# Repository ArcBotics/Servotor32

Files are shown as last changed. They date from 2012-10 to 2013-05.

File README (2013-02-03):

All hardware for Servotor32 is licensed under a Creative Commons Attribution ShareAlike 3.0 United States License.
The full terms of this license can be read at:
http://creativecommons.org/licenses/by-sa/3.0/

All software is licensed under the MIT License.
Permission is hereby granted, free of charge, to any person obtaining a copy of this software and associated documentation files (the "Software"), to deal in the Software without restriction, including without limitation the rights to use, copy, modify, merge, publish, distribute, sublicense, and/or sell copies of the Software, and to permit persons to whom the Software is furnished to do so, subject to the following conditions:

The above copyright notice and this permission notice shall be included in all copies or substantial portions of the Software.

THE SOFTWARE IS PROVIDED "AS IS", WITHOUT WARRANTY OF ANY KIND, EXPRESS OR IMPLIED, INCLUDING BUT NOT LIMITED TO THE WARRANTIES OF MERCHANTABILITY, FITNESS FOR A PARTICULAR PURPOSE AND NONINFRINGEMENT. IN NO EVENT SHALL THE AUTHORS OR COPYRIGHT HOLDERS BE LIABLE FOR ANY CLAIM, DAMAGES OR OTHER LIABILITY, WHETHER IN AN ACTION OF CONTRACT, TORT OR OTHERWISE, ARISING FROM, OUT OF OR IN CONNECTION WITH THE SOFTWARE OR THE USE OR OTHER DEALINGS IN THE SOFTWARE.

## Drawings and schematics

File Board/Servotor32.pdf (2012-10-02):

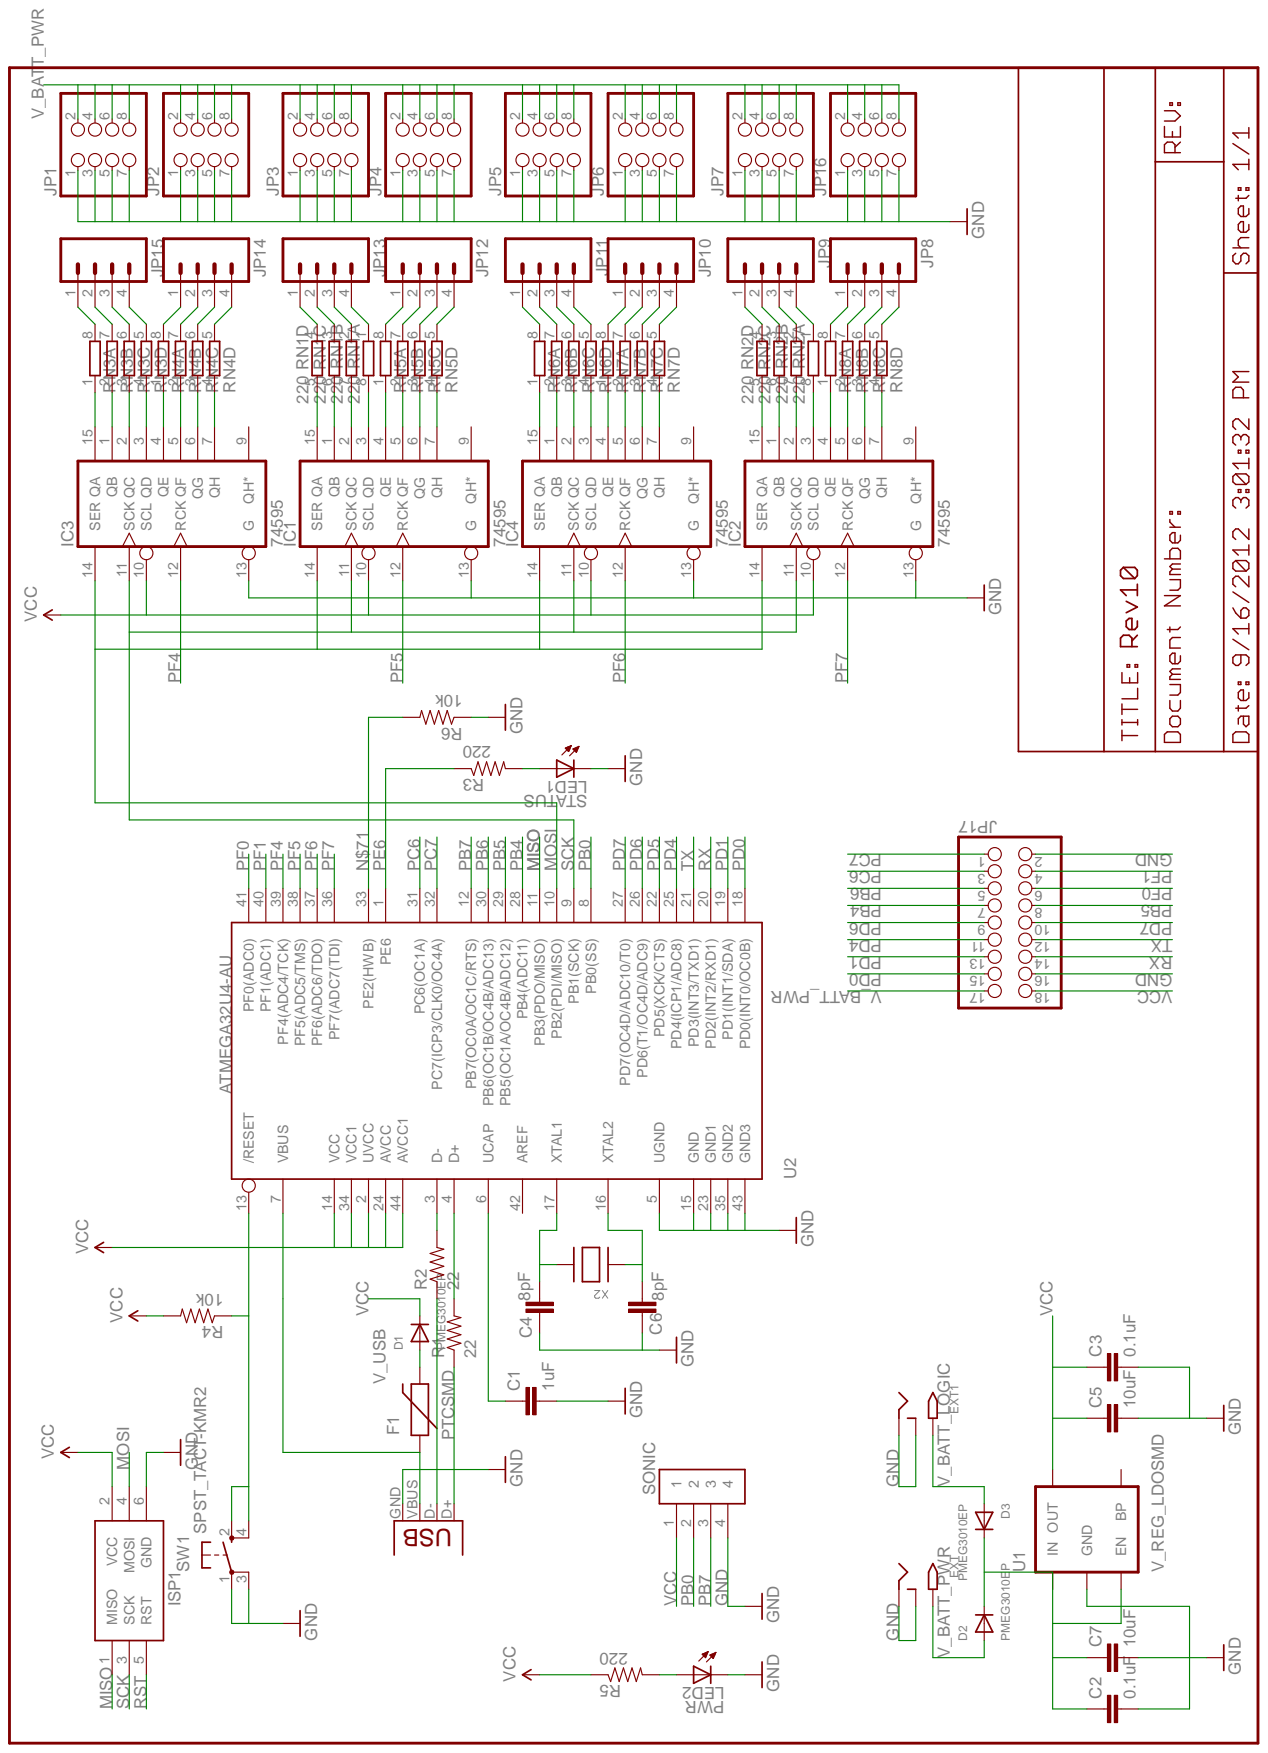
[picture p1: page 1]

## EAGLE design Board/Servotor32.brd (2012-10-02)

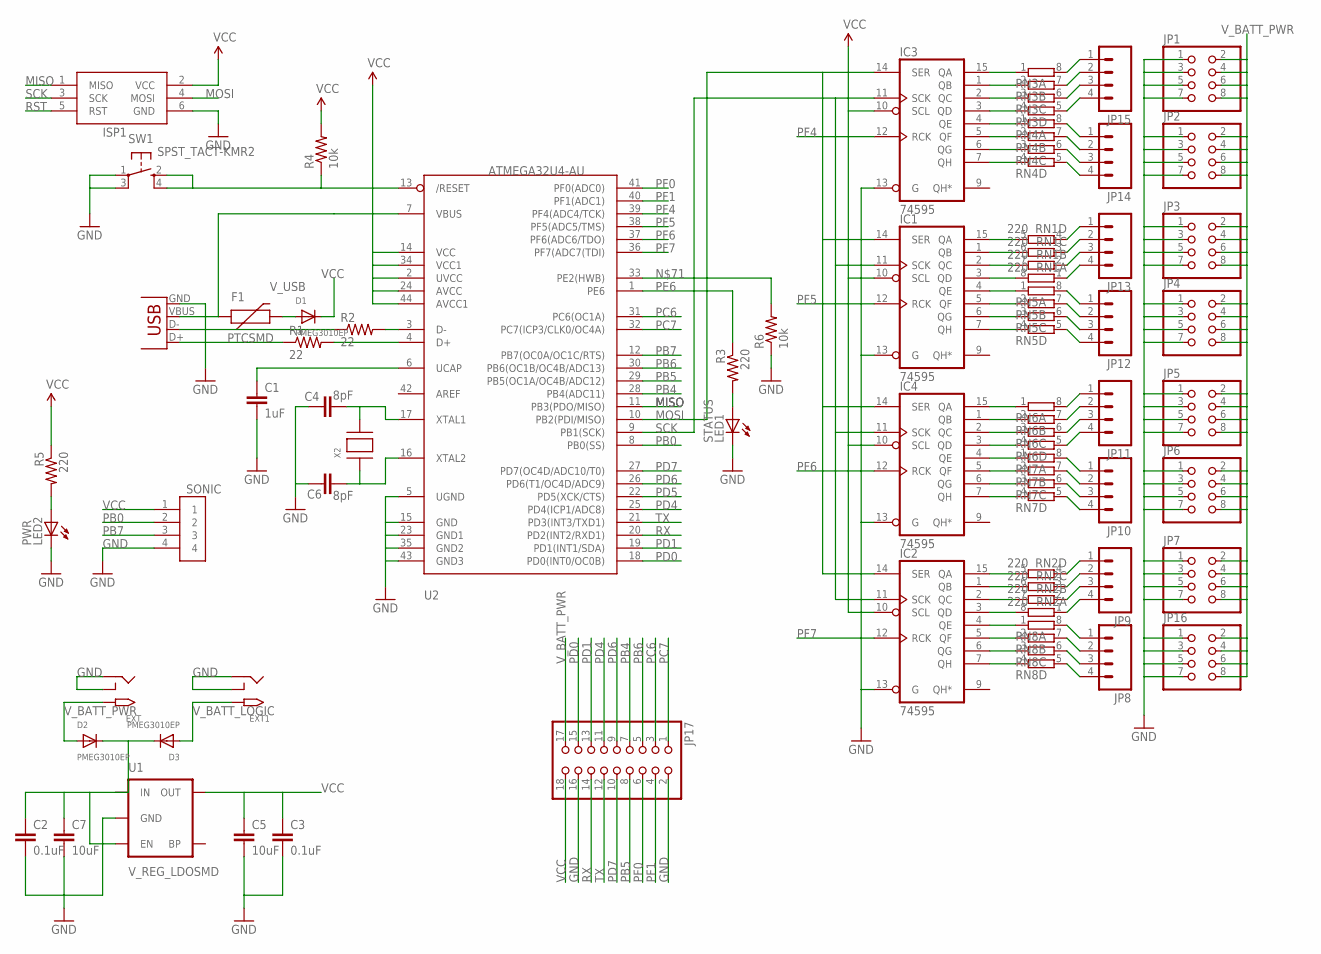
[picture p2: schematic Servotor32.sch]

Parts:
C1: 1uF; 0603-CAP
C2, C3: 0.1uF; 0603-CAP
C4, C6: 8pF; 0603-CAP
C5, C7: 10uF; 0805
D1, D2, D3: PMEG3010EP; SOD-128
EXT, EXT1: 2.1MMJACKTHM; PJ-102A
F1: PTCSMD; PTC-1206
IC1, IC2, IC3, IC4: 74595; TSSOP16
ISP1: AVRISP-6; AVRISP
JP1, JP2, JP3, JP4, JP5, JP6, JP7, JP16: PINHD-2X4; 2X04
JP8, JP9, JP10, JP11, JP12, JP13, JP14, JP15: M04PTH; 1X04
JP17: PINHD-2X9-BIG; 2X09-BIG
LED1: STATUS; SML0805
LED2: PWR; SML0805
R1, R2: 22; 0603-RES
R3, R5: 220; 0603-RES
R4, R6: 10k; 0603-RES
RN1, RN2: 220; EXB38V
RN3, RN4, RN5, RN6, RN7, RN8: 4R-NEXB38V; EXB38V
SONIC: SONIC; 1X04-BIG
SW1: SPST_TACT-KMR2; KMR2
U1: V_REG_LDOSMD; SOT23-5
U2: ATMEGA32U4-AU; TQFP44
X1: USBSMD; USB-MINIB
X2: XTALNX5032; NX5032

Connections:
D+: R1.2, U2.4 (D+)
D-: R2.2, U2.3 (D-)
GND: C1.2, C2.2, C3.2, C4.2, C5.2, C6.2, C7.2, EXT.RING, EXT.RING_SW, EXT1.RING, EXT1.RING_SW, IC1.8 (GND), IC1.13 (G), IC2.8 (GND), IC2.13 (G), IC3.8 (GND), IC3.13 (G), IC4.8 (GND), IC4.13 (G), ISP1.6 (GND), JP1.1, JP1.3, JP1.5, JP1.7, JP2.1, JP2.3, JP2.5, JP2.7, JP3.1, JP3.3, JP3.5, JP3.7, JP4.1, JP4.3, JP4.5, JP4.7, JP5.1, JP5.3, JP5.5, JP5.7, JP6.1, JP6.3, JP6.5, JP6.7, JP7.1, JP7.3, JP7.5, JP7.7, JP16.1, JP16.3, JP16.5, JP16.7, JP17.2, JP17.16, LED1.C, LED2.C, R6.1, SONIC.4, SW1.1, SW1.3 (P1), U1.2 (GND), U2.5 (UGND), U2.15 (GND), U2.23 (GND1), U2.35 (GND2), U2.43 (GND3), X1.GND
MISO: ISP1.1 (MISO), U2.11 (PB3(PDO/MISO))
MOSI: IC1.14 (SER), IC2.14 (SER), IC3.14 (SER), IC4.14 (SER), ISP1.4 (MOSI), U2.10 (PB2(PDI/MISO))
unnamed: IC3.15 (QA), RN3.1
unnamed: LED2.A, R5.2
unnamed: IC1.3 (QD), RN1.8 (2)
unnamed: R2.1, X1.D-
unnamed: R1.1, X1.D+
unnamed: IC2.3 (QD), RN2.8 (2)
unnamed: IC1.2 (QC), RN1.7 (2)
unnamed: IC2.2 (QC), RN2.7 (2)
unnamed: IC1.1 (QB), RN1.6 (2)
unnamed: IC3.1 (QB), RN3.2 (1)
unnamed: IC1.15 (QA), RN1.5 (2)
unnamed: IC3.2 (QC), RN3.3 (1)
unnamed: IC3.3 (QD), RN3.4 (1)
unnamed: IC2.1 (QB), RN2.6 (2)
unnamed: IC2.15 (QA), RN2.5 (2)
unnamed: IC3.4 (QE), RN4.1
unnamed: IC3.5 (QF), RN4.2 (1)
unnamed: IC3.6 (QG), RN4.3 (1)
unnamed: IC3.7 (QH), RN4.4 (1)
unnamed: IC1.4 (QE), RN5.1
unnamed: IC1.5 (QF), RN5.2 (1)
unnamed: JP13.1, RN1.4 (1)
unnamed: IC1.6 (QG), RN5.3 (1)
unnamed: IC1.7 (QH), RN5.4 (1)
unnamed: JP12.1, RN5.8 (2)
unnamed: JP13.2, RN1.3 (1)
unnamed: JP13.3, RN1.2 (1)
unnamed: JP13.4, RN1.1
unnamed: JP12.2, RN5.7 (2)
unnamed: JP12.3, RN5.6 (2)
unnamed: JP12.4, RN5.5 (2)
unnamed: JP15.1, RN3.8 (2)
unnamed: JP15.2, RN3.7 (2)
unnamed: JP15.3, RN3.6 (2)
unnamed: JP15.4, RN3.5 (2)
unnamed: JP14.1, RN4.8 (2)
unnamed: JP14.2, RN4.7 (2)
unnamed: JP14.3, RN4.6 (2)
unnamed: JP14.4, RN4.5 (2)
unnamed: JP9.4, RN2.1
unnamed: JP9.3, RN2.2 (1)
unnamed: JP9.2, RN2.3 (1)
unnamed: JP9.1, RN2.4 (1)
unnamed: IC2.4 (QE), RN8.1
unnamed: IC2.5 (QF), RN8.2 (1)
unnamed: IC2.6 (QG), RN8.3 (1)
unnamed: IC2.7 (QH), RN8.4 (1)
unnamed: JP8.1, RN8.8 (2)
unnamed: JP8.2, RN8.7 (2)
unnamed: JP8.3, RN8.6 (2)
unnamed: JP8.4, RN8.5 (2)
unnamed: IC4.1 (QB), RN6.2 (1)
unnamed: IC4.2 (QC), RN6.3 (1)
unnamed: IC4.3 (QD), RN6.4 (1)
unnamed: IC4.4 (QE), RN7.1
unnamed: IC4.5 (QF), RN7.2 (1)
unnamed: IC4.6 (QG), RN7.3 (1)
unnamed: IC4.7 (QH), RN7.4 (1)
unnamed: JP11.1, RN6.8 (2)
unnamed: JP11.2, RN6.7 (2)
unnamed: JP11.3, RN6.6 (2)
unnamed: JP11.4, RN6.5 (2)
unnamed: JP10.1, RN7.8 (2)
unnamed: JP10.2, RN7.7 (2)
unnamed: JP10.3, RN7.6 (2)
unnamed: JP10.4, RN7.5 (2)
unnamed: LED1.A, R3.2
unnamed: R6.2, U2.33 (PE2(HWB))
unnamed: IC4.15 (QA), RN6.1
PB0: SONIC.2, U2.8 (PB0(SS))
PB4: JP17.7, U2.28 (PB4(ADC11))
PB5: JP17.8, U2.29 (PB5(OC1A/OC4B/ADC12))
PB6: JP17.5, U2.30 (PB6(OC1B/OC4B/ADC13))
PB7: SONIC.3, U2.12 (PB7(OC0A/OC1C/RTS))
PC6: JP17.3, U2.31 (PC6(OC1A))
PC7: JP17.1, U2.32 (PC7(ICP3/CLK0/OC4A))
PD0: JP17.15, U2.18 (PD0(INT0/OC0B))
PD1: JP17.13, U2.19 (PD1(INT1/SDA))
PD4: JP17.11, U2.25 (PD4(ICP1/ADC8))
PD5: U2.22 (PD5(XCK/CTS))
PD6: JP17.9, U2.26 (PD6(T1/OC4D/ADC9))
PD7: JP17.10, U2.27 (PD7(OC4D/ADC10/T0))
PE6: R3.1, U2.1 (PE6)
PF0: JP17.6, U2.41 (PF0(ADC0))
PF1: JP17.4, U2.40 (PF1(ADC1))
PF4: IC3.12 (RCK), U2.39 (PF4(ADC4/TCK))
PF5: IC1.12 (RCK), U2.38 (PF5(ADC5/TMS))
PF6: IC4.12 (RCK), U2.37 (PF6(ADC6/TDO))
PF7: IC2.12 (RCK), U2.36 (PF7(ADC7(TDI))
RST: ISP1.5 (RST), R4.1, SW1.2 (S), SW1.4 (S1), U2.13 (/RESET)
RX: JP17.14, U2.20 (PD2(INT2/RXD1))
SCK: IC1.11 (SCK), IC2.11 (SCK), IC3.11 (SCK), IC4.11 (SCK), ISP1.3 (SCK), U2.9 (PB1(SCK))
TX: JP17.12, U2.21 (PD3(INT3/TXD1))
UCAP: C1.1, U2.6 (UCAP)
VBUS: F1.1, U2.7 (VBUS), X1.VBUS
VCC: C3.1, C5.1, D1.P$1 (C), IC1.10 (SCL), IC1.16 (VCC), IC2.10 (SCL), IC2.16 (VCC), IC3.10 (SCL), IC3.16 (VCC), IC4.10 (SCL), IC4.16 (VCC), ISP1.2 (VCC), JP17.18, R4.2, R5.1, SONIC.1, U1.5 (OUT), U2.2 (UVCC), U2.14 (VCC), U2.24 (AVCC), U2.34 (VCC1), U2.44 (AVCC1)
V_BATT: C2.1, C7.1, D2.P$1 (C), D3.P$1 (C), U1.1 (IN), U1.3 (EN)
V_BATT_LOGIC: D3.P$2 (A), EXT1.TIP
V_BATT_PWR: D2.P$2 (A), EXT.TIP, JP1.2, JP1.4, JP1.6, JP1.8, JP2.2, JP2.4, JP2.6, JP2.8, JP3.2, JP3.4, JP3.6, JP3.8, JP4.2, JP4.4, JP4.6, JP4.8, JP5.2, JP5.4, JP5.6, JP5.8, JP6.2, JP6.4, JP6.6, JP6.8, JP7.2, JP7.4, JP7.6, JP7.8, JP16.2, JP16.4, JP16.6, JP16.8, JP17.17
V_USB: D1.P$2 (A), F1.2
XTAL1: C4.1, U2.17 (XTAL1), X2.P$2
XTAL2: C6.1, U2.16 (XTAL2), X2.P$1

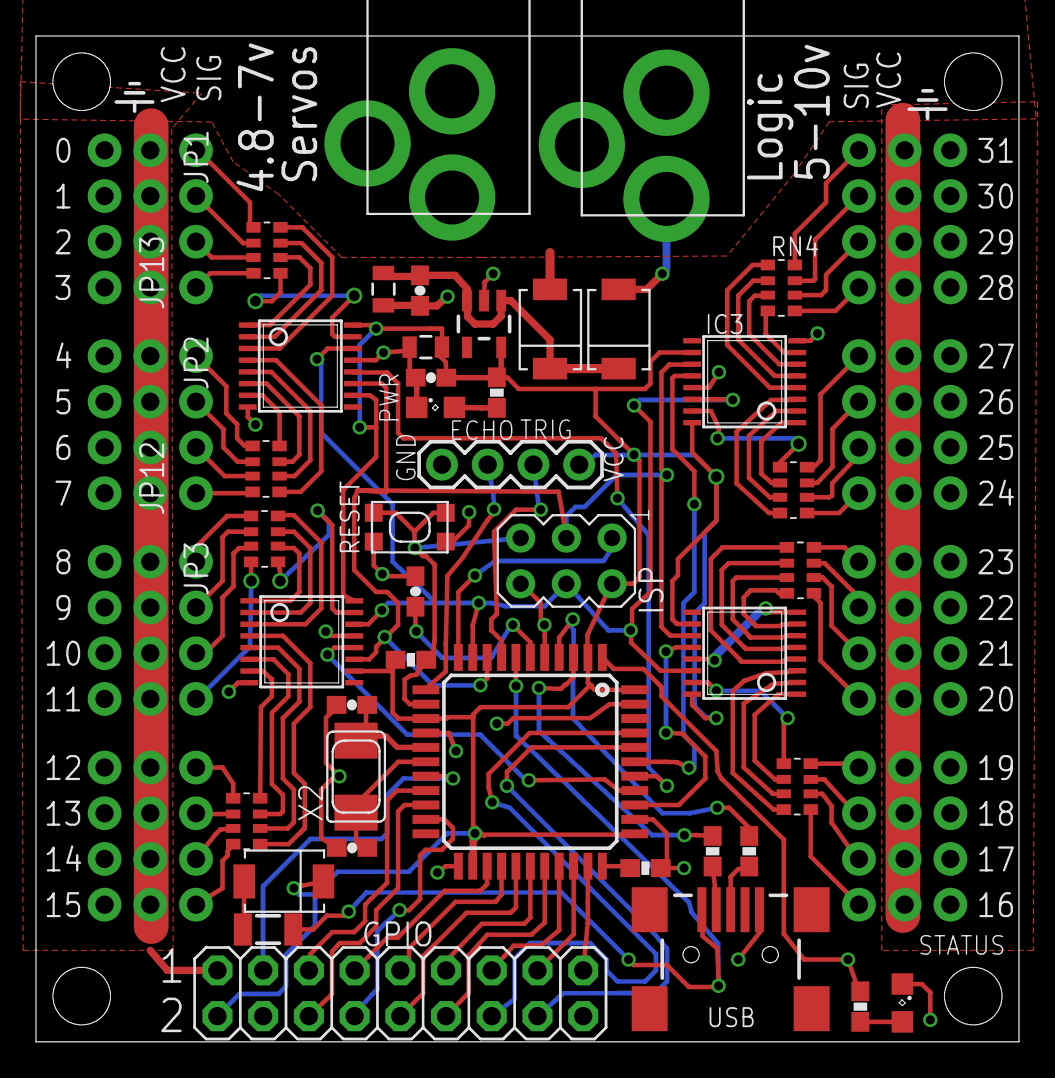
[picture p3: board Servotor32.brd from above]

Board: 2 copper layers, 54.6 x 55.9 mm, 57 parts (0 on the bottom side), 106 nets.

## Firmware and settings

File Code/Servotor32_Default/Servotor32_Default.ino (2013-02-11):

#include "Servotor32.h" // call the servotor32 Library
Servotor32 hexy; // create a servotor32 object

void setup() {
  hexy.begin();
}

void loop() {
  // blink the status led
  digitalWrite(STATUS_LED, HIGH);
  hexy.delay_ms(500); // wait 500mS
  digitalWrite(STATUS_LED, LOW);
  hexy.delay_ms(500); // wait 500mS
  
  // kill all servos
  for(int i=0; i<32; i++){
    hexy.changeServo(i,-1);
  }
  
  // center servos 0,1,2,3
  hexy.changeServo(0,1500);
  hexy.changeServo(1,1500);
  hexy.changeServo(2,1500);
  hexy.changeServo(3,1500);
  
  hexy.delay_ms(100); // wait 100mS
 
  while(true){
    // get a ping from the ultrasonic sensor in CM
    //Serial.print("CM: ");
    //Serial.println(hexy.ping());
    //hexy.delay_ms(200); // wait 200mS
    
    hexy.process(&Serial); //process input from the USB
    hexy.process(&Serial1); //process input from the board serial (i.e. bluetooth)
  }
  
}

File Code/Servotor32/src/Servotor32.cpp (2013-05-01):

#include "Servotor32.h"
#include <inttypes.h>
#include <stdio.h>
#include <string.h>
#include "Arduino.h"

#include "Servotor32_SPI.h"
#include "Servotor32_TimerOne.h"

Servotor32::Servotor32()
{  

}

//stores information about the servos and groups
signed short servo_positions[SERVOS]; // where the servos are currently (supposed to be) at
signed char servos_sorted[GROUPS][SERVOS_PER_GROUP]; // index in servo_timings to where the servo ends
signed char servos_active_in_group[GROUPS]; // the number of servos in a group currently active
uint8_t active_servos_hex[GROUPS];

// all updates to shift registers in order of their updates
signed short servo_timings[MAX_TIMINGS]; // the timing where the change occurs
uint8_t  shift_output[MAX_TIMINGS];  // the output of the shift register
uint8_t  shift_latch[MAX_TIMINGS];   // the shift register latch used

// keeps track of whether its safe or not to update the servos
uint8_t update_reg_flag = 0;

// variables for the callback
uint16_t timer;
uint8_t  counter = 0;
uint8_t  pwm_active = 1;

uint16_t group_offsets[4] = {0,251,502,753};
uint8_t group_latches[4] = {5,6,7,4};
uint8_t pin_2_num[8] = {0x08,0x04,0x02,0x01, 0x80,0x40,0x20,0x10};

void Servotor32::begin(){
  //setup pin modes
  DDRF |= 0xF0;  // sets pins F7 to F4 as outputs
  DDRB = 0xFF;  // sets pins B0 to B7 as outputs
  
  //setup PC serial port
  Serial.begin(9600);
  // reconfigure bluetooth module to 9600 baud id needed
  Serial1.begin(115200);     // Changed from 9600 baud
  Serial1.print("AT+BAUD4"); // Tell the module to change the baud rate to 9600
  delay(1100); // Wait a notch over 1 second to make sure the setting "sticks"
  Serial1.begin(9600);     // Changed from 9600 baud
  
  SPI.begin(); 
  SPI.setClockDivider(SPI_CLOCK_DIV2); 

  Timer1.initialize(10);
  Timer1.attachInterrupt(callback);

  for(byte i=0; i<SERVOS; i++){
    servo_positions[i] = -1;
  }
  for(byte i=0; i<GROUPS; i++){
    for(byte j=0; j<SERVOS_PER_GROUP; j++){
      servos_sorted[i][j] = -1;
    }
  }
  
  for(uint8_t i=0; i<MAX_TIMINGS; i++){
    servo_timings[i] = 0;
    shift_output[i] = 0xFF;
    shift_latch[i] = 0xFF;
  } 

  TIMSK0 &= ~(_BV(TOIE0)); // disables the arduino delay function, but also
                           // all but eliminates servo jitter 
  TIMSK2 &= ~(_BV(TOIE2)); // disable the arduino tone  function, but also
                           // also helps eliminate some jitter
  TIMSK3 &= ~(_BV(TOIE3)); // for good measure
  TIMSK4 &= ~(_BV(TOIE4)); // for good measure 
}

long unsigned int us_counter = 0;
long unsigned int startTime = 0; 
long unsigned int currentTime = 0; 
long unsigned int last_update = 0;

long unsigned int Servotor32::micros_new(){
  return us_counter;
}

long unsigned int Servotor32::millis_new(){
  return us_counter/1000;
}

void Servotor32::delay_ms(long unsigned int delay_time){
  startTime = millis_new();
  currentTime = millis_new() - startTime;
  while(currentTime < delay_time){
    delayMicroseconds(10);
    currentTime = millis_new() - startTime;
  }
}

void Servotor32::delay_us(long unsigned int delay_time){
  startTime = micros_new();
  currentTime = micros_new() - startTime;
  while(currentTime < delay_time){
    delayMicroseconds(10);
    currentTime = micros_new() - startTime;
  }
}

void Servotor32::callback(){
  cli();
  if(timer < 1100){ // keep it from updating servos mid-array change by some weird coincidence
    if(timer == servo_timings[counter]){ // if the time has arrived to update a shift reg
      SPDR = shift_output[counter]; // push the byte to be loaded to the SPI register
      while(!(SPSR & (1<<SPIF))); //wait till the register completes
      PORTF &= ~(shift_latch[counter]); // clock the shift register latch pin low, setting the register
      PORTF |= shift_latch[counter];  // clock the shift register latch pin high, ready to be set low next time
      counter++;
    }
  }

  timer++;
  us_counter += 10;
  if(timer == 1100){ // all servo timing completed
    update_reg_flag = 1; // allow updates to the timing arrays
  }
  if(timer == 1900){ // getting close to servo start-up again,
    update_reg_flag = 0; // don't allow any new timing array updates
  }
  if(timer == 2000){
    timer=0;
    counter=0;
  }
  sei();
}

void Servotor32::delete_from_sorted_array(byte servo, byte group, signed short pos){
  for(byte i=0; i<servos_active_in_group[group]; i++){ // go through all the servos
    if(servos_sorted[group][i] == servo){ // find its place
       for(signed char j=i; j<servos_active_in_group[group]-1; j++){//move all servos in front of it back by one
         servos_sorted[group][j] = servos_sorted[group][j+1];
       }
       servos_sorted[group][servos_active_in_group[group]-1] = -1; //insert a -1 at the end of the move
       break; //break out of previous for loop, now that the job is done
    }
  }
  active_servos_hex[group] &= ~pin_2_num[servo-group*SERVOS_PER_GROUP];
  servos_active_in_group[group] -= 1;// decrease the number of active servos in the group by 1
}

void Servotor32::add_to_sorted_array(byte servo, byte group, signed short pos){
  for(byte i=0; i<=servos_active_in_group[group]; i++){ // find the servo
     if(servos_sorted[group][i] == -1){ // if no servos yet entered, set as first
       servos_sorted[group][i] = servo; //insert the servo in its sorted place
       break; //stop the for loop, as the job is done
     }
     else{
       if(servo_positions[servos_sorted[group][i]] > pos){ // if this servo should go before this one
         for(signed char j=servos_active_in_group[group]-1; j>=i; j--){// move all others forward one
           servos_sorted[group][j+1] = servos_sorted[group][j];
         }
         servos_sorted[group][i] = servo; //insert the servo in its sorted place
         break;
       }
     }
  }
  active_servos_hex[group] |= pin_2_num[servo-group*SERVOS_PER_GROUP];
  servos_active_in_group[group] += 1;
}
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

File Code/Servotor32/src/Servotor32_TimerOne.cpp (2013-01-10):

/*
 *  Interrupt and PWM utilities for 16 bit Timer1 on ATmega168/328
 *  Original code by Jesse Tane for http://labs.ideo.com August 2008
 *  Modified March 2009 by Jérôme Despatis and Jesse Tane for ATmega328 support
 *  Modified June 2009 by Michael Polli and Jesse Tane to fix a bug in setPeriod() which caused the timer to stop
 *  Modified June 2011 by Lex Talionis to add a function to read the timer
 *
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
 *  See Google Code project http://code.google.com/p/arduino-DBStepper_TimerOne/ for latest
 */
#ifndef Servotor32TimerOne_cpp
#define Servotor32_TimerOne_cpp

#include "Servotor32_TimerOne.h"

Servotor32_TimerOne Timer1;              // preinstatiate

ISR(TIMER1_OVF_vect)          // interrupt service routine that wraps a user defined function supplied by attachInterrupt
{
  Timer1.isrCallback();
}

void Servotor32_TimerOne::initialize(long microseconds)
{
  TCCR1A = 0;                 // clear control register A 
  TCCR1B = _BV(WGM13);        // set mode 8: phase and frequency correct pwm, stop the timer
  setPeriod(microseconds);
}

void Servotor32_TimerOne::setPeriod(long microseconds)
{
  long cycles = (F_CPU / 2000000) * microseconds;                                // the counter runs backwards after TOP, interrupt is at BOTTOM so divide microseconds by 2
  if(cycles < RESOLUTION)              clockSelectBits = _BV(CS10);              // no prescale, full xtal
  else if((cycles >>= 3) < RESOLUTION) clockSelectBits = _BV(CS11);              // prescale by /8
  else if((cycles >>= 3) < RESOLUTION) clockSelectBits = _BV(CS11) | _BV(CS10);  // prescale by /64
  else if((cycles >>= 2) < RESOLUTION) clockSelectBits = _BV(CS12);              // prescale by /256
  else if((cycles >>= 2) < RESOLUTION) clockSelectBits = _BV(CS12) | _BV(CS10);  // prescale by /1024
  else        cycles = RESOLUTION - 1, clockSelectBits = _BV(CS12) | _BV(CS10);  // request was out of bounds, set as maximum
  ICR1 = pwmPeriod = cycles;                                                     // ICR1 is TOP in p & f correct pwm mode
  TCCR1B &= ~(_BV(CS10) | _BV(CS11) | _BV(CS12));
  TCCR1B |= clockSelectBits;                                                     // reset clock select register
}

void Servotor32_TimerOne::setPwmDuty(char pin, int duty)
{
  unsigned long dutyCycle = pwmPeriod;
  dutyCycle *= duty;
  dutyCycle >>= 10;
  if(pin == 1 || pin == 9)       OCR1A = dutyCycle;
  else if(pin == 2 || pin == 10) OCR1B = dutyCycle;
}

void Servotor32_TimerOne::pwm(char pin, int duty, long microseconds)  // expects duty cycle to be 10 bit (1024)
{
  if(microseconds > 0) setPeriod(microseconds);
  if(pin == 1 || pin == 9) {
    DDRB |= _BV(PORTB1);                                   // sets data direction register for pwm output pin
    TCCR1A |= _BV(COM1A1);                                 // activates the output pin
  }
  else if(pin == 2 || pin == 10) {
    DDRB |= _BV(PORTB2);
    TCCR1A |= _BV(COM1B1);
  }
  setPwmDuty(pin, duty);
  start();
}

void Servotor32_TimerOne::disablePwm(char pin)
{
  if(pin == 1 || pin == 9)       TCCR1A &= ~_BV(COM1A1);   // clear the bit that enables pwm on PB1
  else if(pin == 2 || pin == 10) TCCR1A &= ~_BV(COM1B1);   // clear the bit that enables pwm on PB2
}

void Servotor32_TimerOne::attachInterrupt(void (*isr)(), long microseconds)
{
  if(microseconds > 0) setPeriod(microseconds);
  isrCallback = isr;                                       // register the user's callback with the real ISR
  TIMSK1 = _BV(TOIE1);                                     // sets the timer overflow interrupt enable bit
  sei();                                                   // ensures that interrupts are globally enabled
  start();
}

void Servotor32_TimerOne::detachInterrupt()
{
  TIMSK1 &= ~_BV(TOIE1);                                   // clears the timer overflow interrupt enable bit 
}

void Servotor32_TimerOne::start()
{
  TCCR1B |= clockSelectBits;
}

void Servotor32_TimerOne::stop()
{
  TCCR1B &= ~(_BV(CS10) | _BV(CS11) | _BV(CS12));          // clears all clock selects bits
}

void Servotor32_TimerOne::restart()
{
  TCNT1 = 0;
}

unsigned long Servotor32_TimerOne::read()		//returns the value of the timer in microseconds
{									//rember! phase and freq correct mode counts up to then down again
	unsigned int tmp=TCNT1;
	char scale=0;
	switch (clockSelectBits)
	{
	case 1:// no prescalse
		scale=0;
		break;
	case 2:// x8 prescale
		scale=3;
		break;
	case 3:// x64
		scale=6;
		break;
	case 4:// x256
		scale=8;
		break;
	case 5:// x1024
		scale=10;
		break;
	}
	while (TCNT1==tmp) //if the timer has not ticked yet
	{
		//do nothing -- max delay here is ~1023 cycles
	}
	tmp = (  (TCNT1>tmp) ? (tmp) : (ICR1-TCNT1)+ICR1  );//if we are counting down add the top value to how far we have counted down
	return ((tmp*1000L)/(F_CPU /1000L))<<scale;
}

#endif

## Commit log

2012-04-15 Rev 4
    [Servitor32.brd, Servitor32.sch]
2012-10-02 Rev10 Update for Production
    [Servitor32.brd, Servitor32.sch, Servotor32.brd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]
2012-10-26 Servotor32 1.4 firmware update
2012-10-26 Servotor32 Firmware 1.3 update
2012-10-26 added new fuse settings
2012-10-30 1.5 update, way less shaking, near-instant servo command handling
2012-12-25 Servotor 1.7 Update, stable servos
2013-01-10 Servotor 2.0 Update. Backend hiding, library-based, new change engine
2013-01-23 Used streams for Serial and Serial1 so print messages are common.
2013-04-02 Fixed include to have the correct casing.
    Fixed include to allow compiling the code on a case-sensitive filesystem.
    [Servotor32.cpp]
2016-05-21 Updated library to Arduino 1.6 library specs

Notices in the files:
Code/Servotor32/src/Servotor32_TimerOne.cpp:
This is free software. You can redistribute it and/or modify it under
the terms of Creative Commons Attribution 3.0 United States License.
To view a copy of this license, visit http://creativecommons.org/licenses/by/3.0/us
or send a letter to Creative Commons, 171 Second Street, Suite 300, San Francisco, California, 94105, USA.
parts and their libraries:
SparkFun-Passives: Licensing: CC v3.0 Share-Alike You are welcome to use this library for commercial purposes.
